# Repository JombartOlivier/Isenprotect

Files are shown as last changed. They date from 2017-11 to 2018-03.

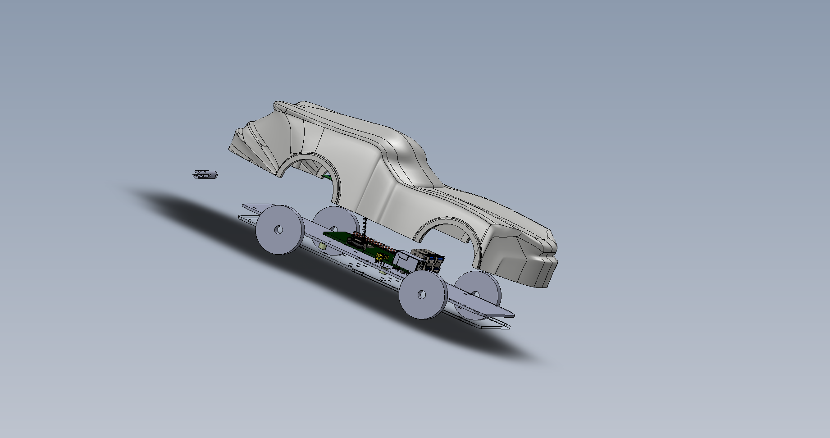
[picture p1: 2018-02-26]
Solidworks/VOITURE2.PNG

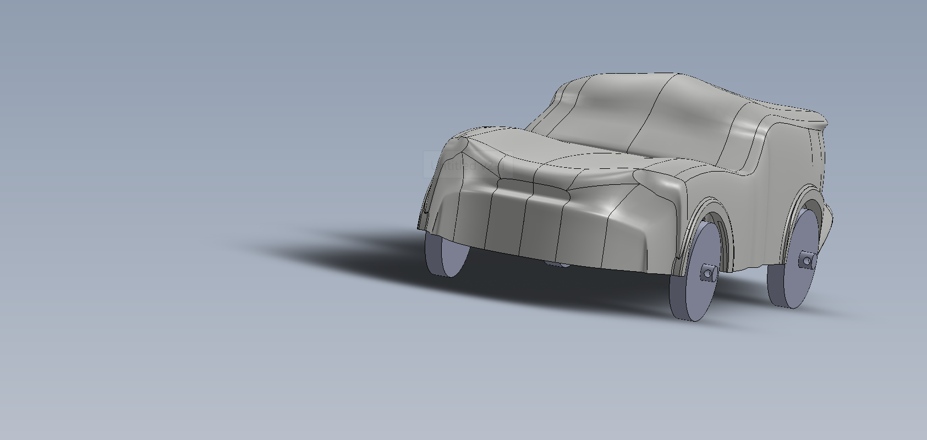
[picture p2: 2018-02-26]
Solidworks/VOITURE.PNG

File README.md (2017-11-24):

IsenProtect
==
Goal
-
The goal of this project is to make a devices who save your life in case of a car accident. 
We make a crash dectetor whit a IMU 6 axis if a crash is dected and the user don't press a buttons in 1 minute after the crash.
The devices send an alert the rescuer.
The project is a Isen Project.

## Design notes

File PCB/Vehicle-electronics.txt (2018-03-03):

- le nom de l'archive d¨¦pos¨¦e
Vehicle-electronics

- les dimensions approximatives du circuit (pour v¨¦rification apr¨¨s importation)
57.2 x 86.5mm

- le nombre d'exemplaires d¨¦sir¨¦s
2

- le mail du r¨¦f¨¦rent projet (encadrant)
annemarie.kokosy@yncrea.fr

- le mail du responsable technique, c'est ¨¤ dire la personne ¨¤ contacter en cas de probl¨¨me lors de la r¨¦alisation du circuit
cong.chen@isen.yncrea.fr

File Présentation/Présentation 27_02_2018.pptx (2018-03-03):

## ISENPROTECT

Olivier Jombart / Cong Chen / Arthur Duystchaever

## Sommaire

1. Objectifs
2. Concept
3. Ordinateur embarqué
4. Détecteur de chocs
5. GPS
6. Transmission des données
7. Autres fonctionnalités
8. Intégration

## Objectifs

- Concevoir un système capable d’émettre un SOS en cas d’accident
- Diminuer le temps entre la détection de l’accident et l’intervention des secours
- Diminuer le risque de mortalité sur la route

## Concept

GPS

Capteur de chocs

Processeur

Envoie des coordonnées GPS

Button momentanné

Avertisseur Sonore

## Ordinateur embarqué

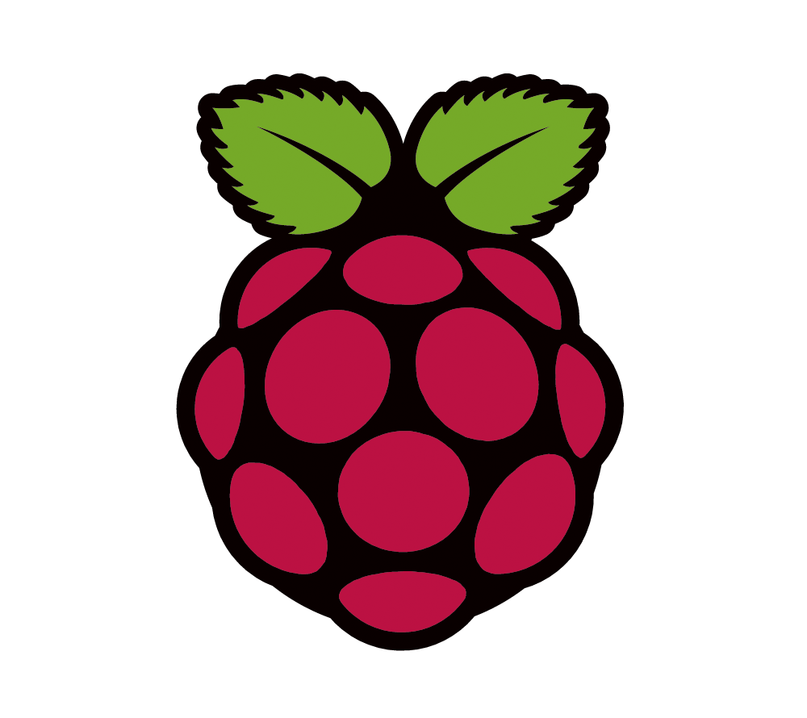
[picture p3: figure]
Résultat de recherche d'images pour "raspberry pi3 logo png"

- Raspberry PI3
- OS : Raspbian
- Processeur : ARM Quad Core 1,2 GHz

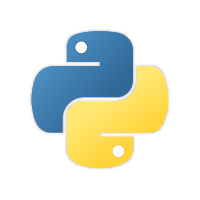
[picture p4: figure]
Résultat de recherche d'images pour "python"
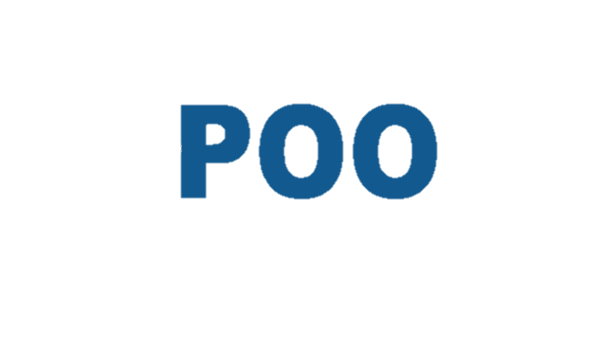
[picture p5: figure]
Résultat de recherche d'images pour "orienté objet"

## Détecteur de chocs

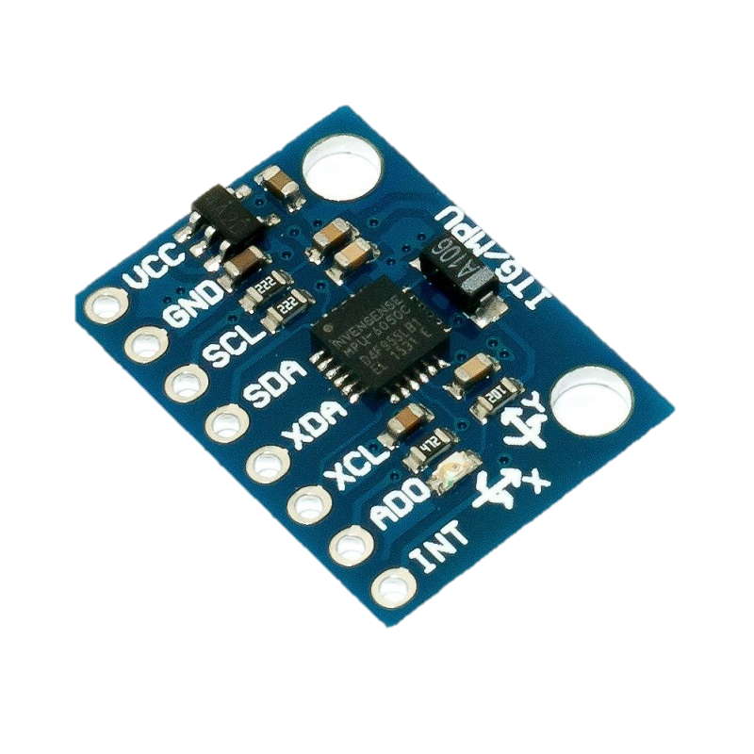
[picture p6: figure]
Résultat de recherche d'images pour "mpu6050 ITG"

- MPU6050 (ITG)
- Communication : I2C
- IMU 6 axes : accéléromètre, gyroscope

## GPS

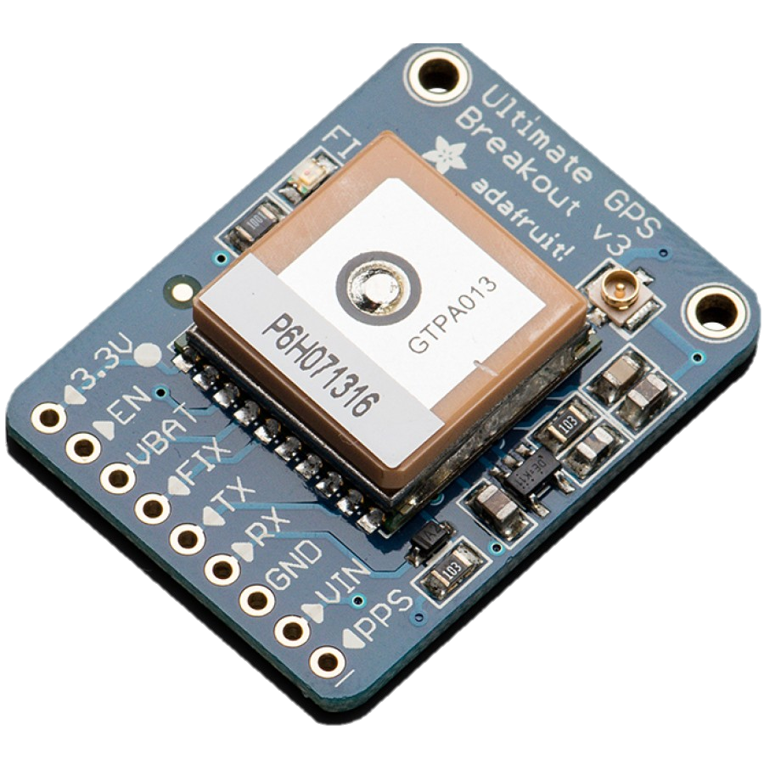
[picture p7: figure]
Résultat de recherche d'images pour "gps adafruit png"

- GPS : Adafruit 746
- Communication : UART
- Baud Rate : 9600

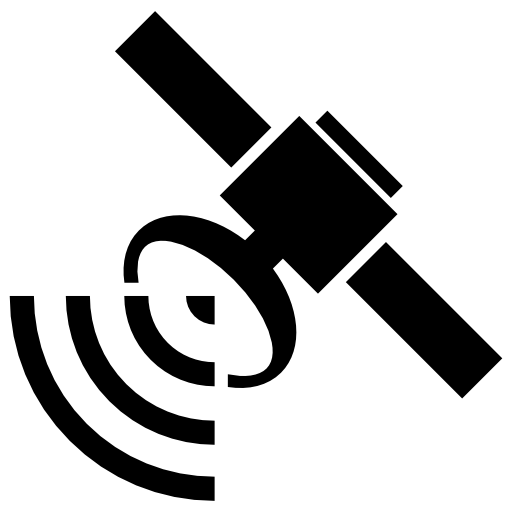
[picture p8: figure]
Résultat de recherche d'images pour "GPS PNG"

$GPRMC,194509.000,A,4042.6142,N,07400.4168,E,2.03,221.11,280218,,,A*77

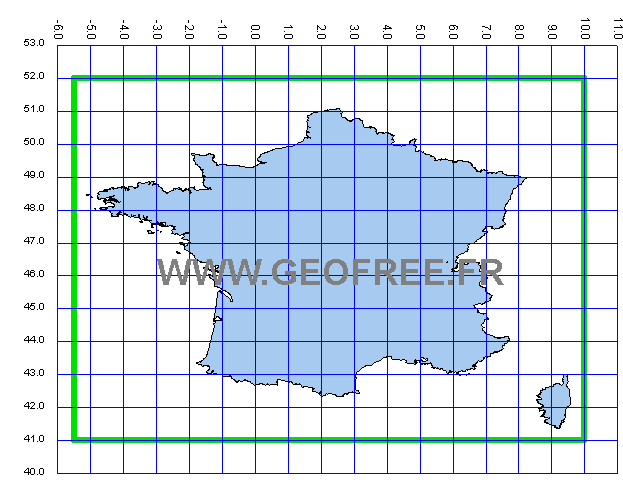
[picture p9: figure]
Résultat de recherche d'images pour "france coordonnées géographique"

## Transmission des données

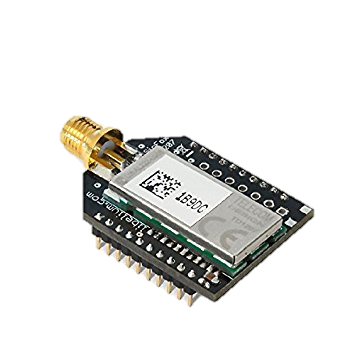
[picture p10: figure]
Résultat de recherche d'images pour "module sigfox"

- SigFox
- Communication : UART
- Baud Rate : 115200

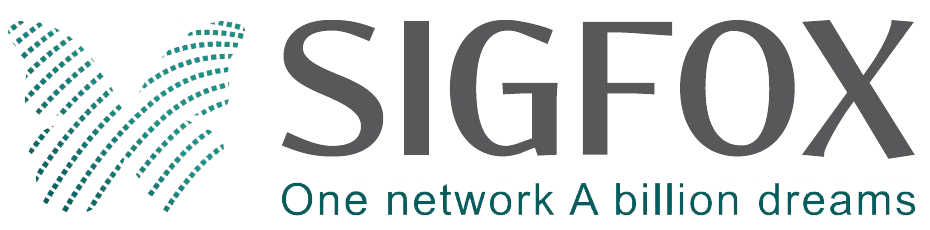
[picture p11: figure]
Résultat de recherche d'images pour "sigfox png"
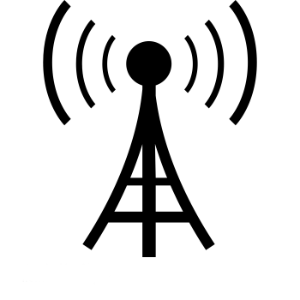
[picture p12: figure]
Résultat de recherche d'images pour "antennes png"
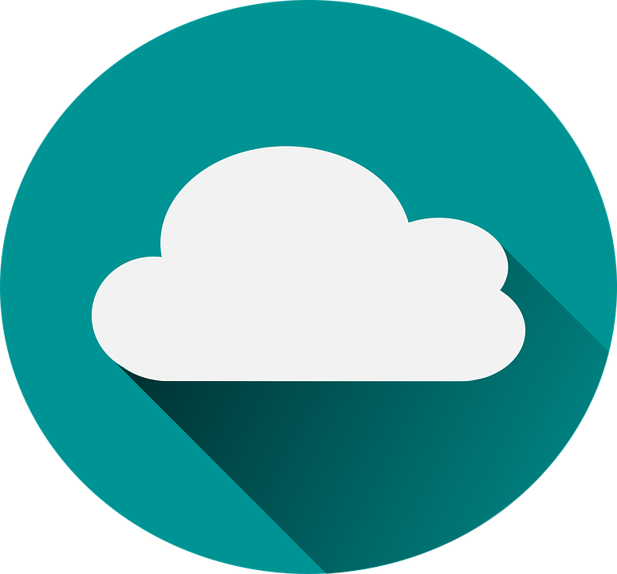
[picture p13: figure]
Résultat de recherche d'images pour "cloud logo png"
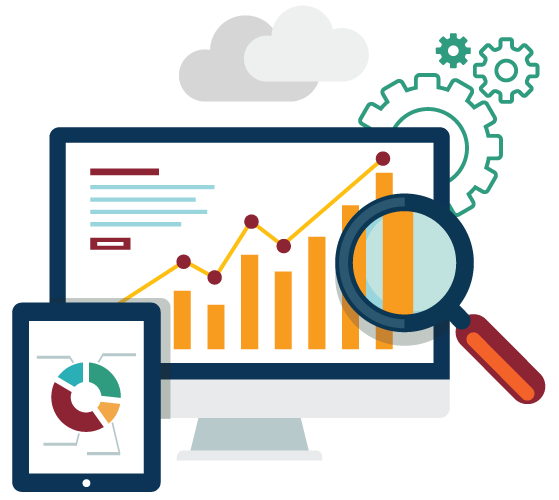
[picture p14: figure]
Résultat de recherche d'images pour "monitoring png"

## Autres fonctionnalités

- Bouton Momentané avec LED intégré
- Avertisseur sonore

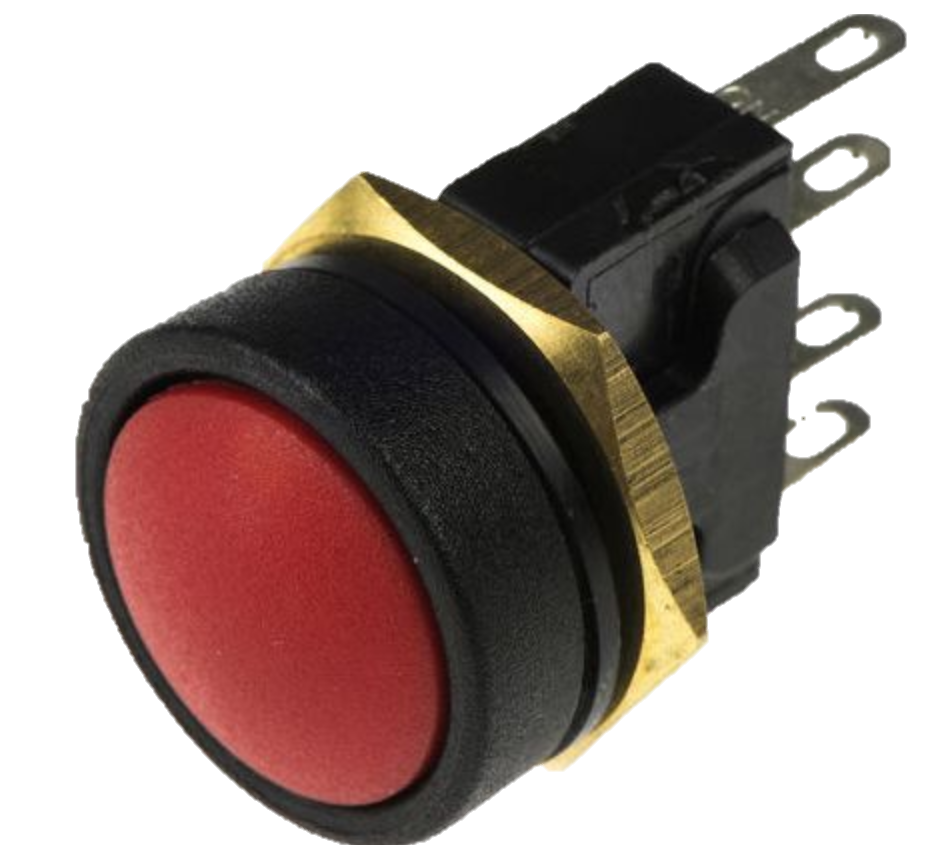
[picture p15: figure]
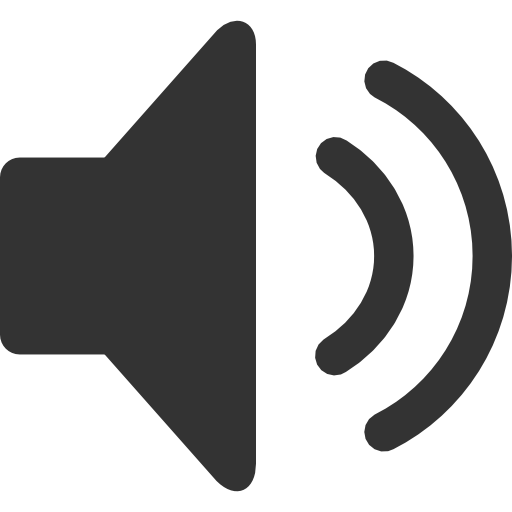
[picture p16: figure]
Résultat de recherche d'images pour "haut parleur png"

## Intégration

GPS

UART : RX-> TX

IMU

I2C

Raspberry + Shield

UART : TX-> RX

Sigfox

GPIO

HDMI ou Jack

Enceintes

Button momentanné

## Conclusion

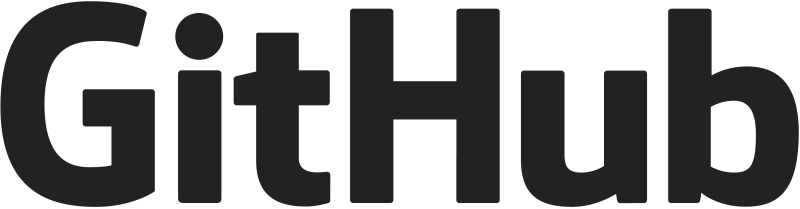
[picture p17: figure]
Résultat de recherche d'images pour "github png"
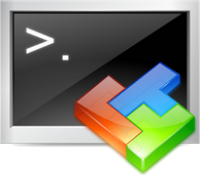
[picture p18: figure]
Résultat de recherche d'images pour "mobaxterm png"
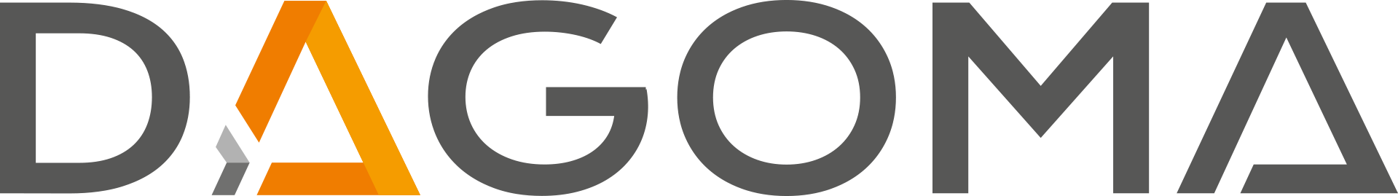
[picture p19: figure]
Résultat de recherche d'images pour "dagoma png"
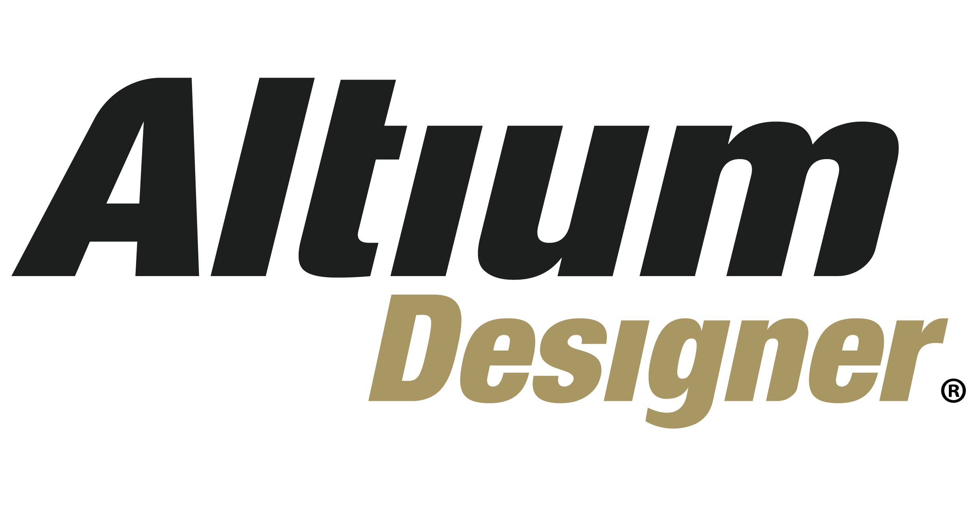
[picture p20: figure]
Résultat de recherche d'images pour "altium designer png"

## Démonstration


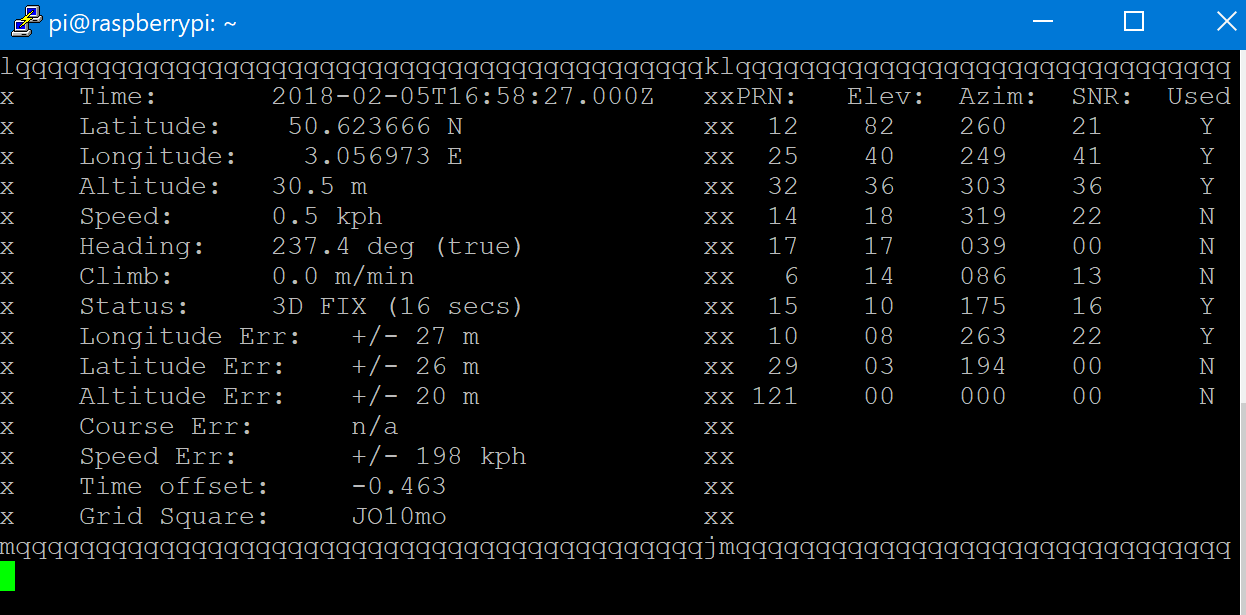
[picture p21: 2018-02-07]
Documentation/GPS WORKS.PNG

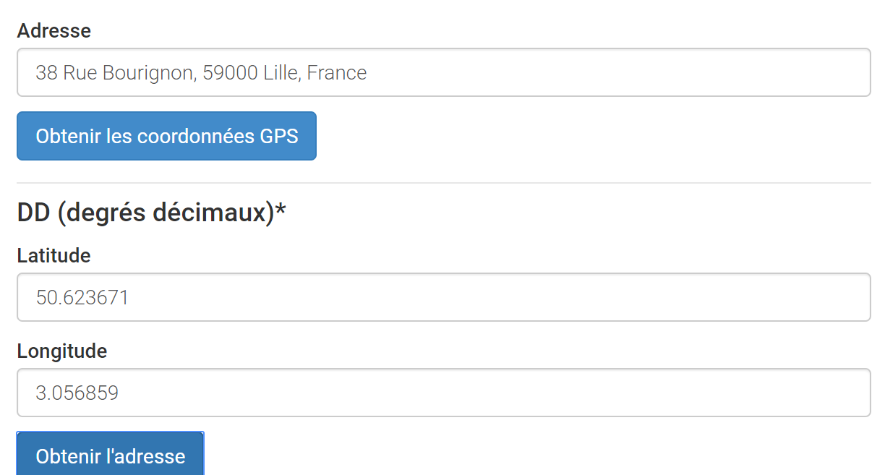
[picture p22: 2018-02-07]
Documentation/GPS2WORKS.PNG

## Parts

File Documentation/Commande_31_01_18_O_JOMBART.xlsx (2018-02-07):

Decription | N° produit | Lien | Quantité | Prix
Radiospare
Bouton Poussoir momentané | 228-4632 | https://fr.rs-online.com/web/p/interrupteurs-a-bouton-poussoir/2284632/ | 1 | 9.52 €
MPU-6050 | 883-7948 | https://fr.rs-online.com/web/p/accelerometres/8837948/ | 3 | 8.19 €
Total |  |  | 4 | 34.09 €

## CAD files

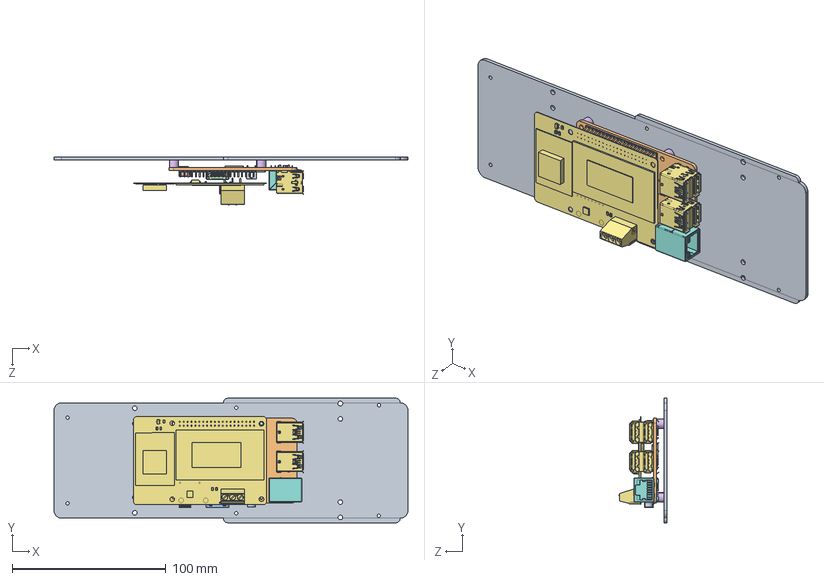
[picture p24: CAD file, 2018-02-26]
Solidworks/Assemblage socle rasp.SLDASM
230.0 x 81.0 x 31.5 mm
socle
carte_mere
HDMI_socket_cover
HDMI_socket_inside
HDMI_socket_large_pin x 10
HDMI_socket_small_pin x 9
usb3x2 x 2
RJ45_10P_TJ3009
PCB_Stereo_Jack_(body)
PCB_Stereo_Jack_(GND_contact)
PCB_Stereo_Jack_(channel_contact_2)
PCB_Stereo_Jack_(channel_contact_1)
USB
Pièce espacement raspberry pi x 4
vehicle electronics

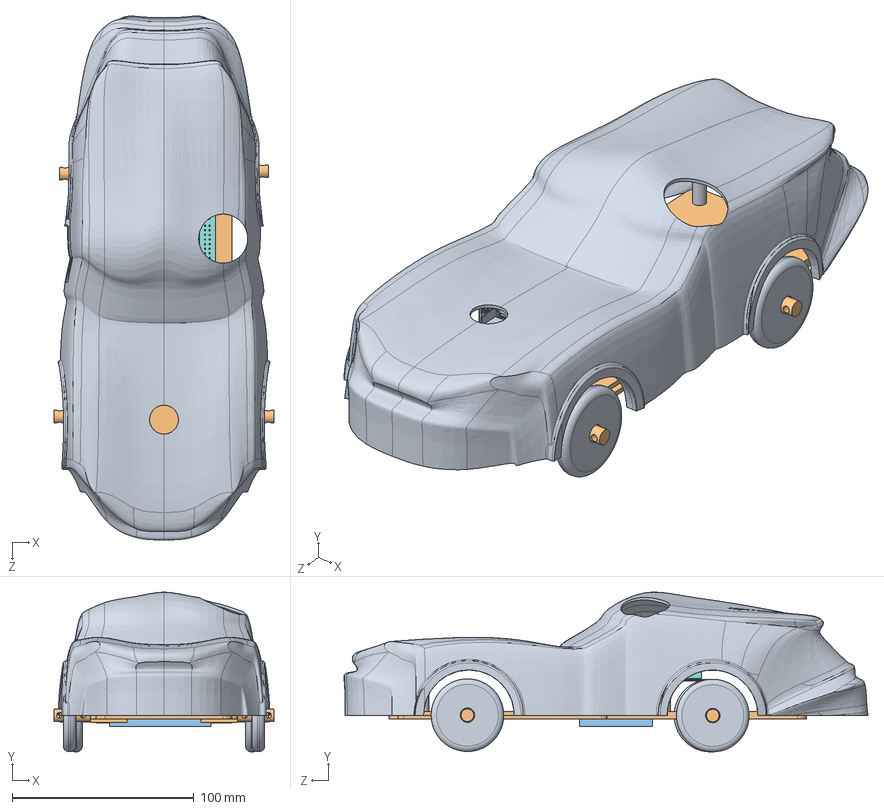
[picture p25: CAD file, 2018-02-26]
Solidworks/Assemblage finale.SLDASM
121.0 x 88.0 x 288.7 mm
Coqueavant
socle
carte_mere
HDMI_socket_cover
HDMI_socket_inside
HDMI_socket_large_pin x 10
HDMI_socket_small_pin x 9
usb3x2 x 2
RJ45_10P_TJ3009
PCB_Stereo_Jack_(body)
PCB_Stereo_Jack_(GND_contact)
PCB_Stereo_Jack_(channel_contact_2)
PCB_Stereo_Jack_(channel_contact_1)
USB
Pièce espacement raspberry pi x 4
vehicle electronics
Wheel x 4
Arbre x 4
Support socle x 2

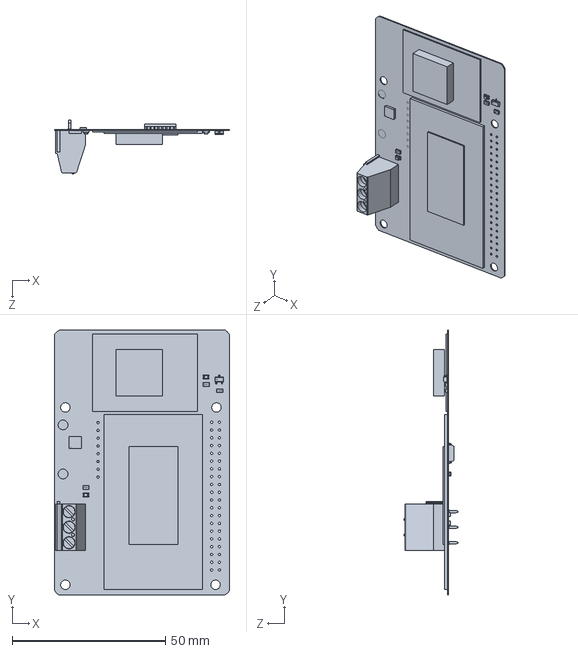
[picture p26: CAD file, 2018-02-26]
Solidworks/vehicle electronics.SLDPRT
57.2 x 86.5 x 17.7 mm

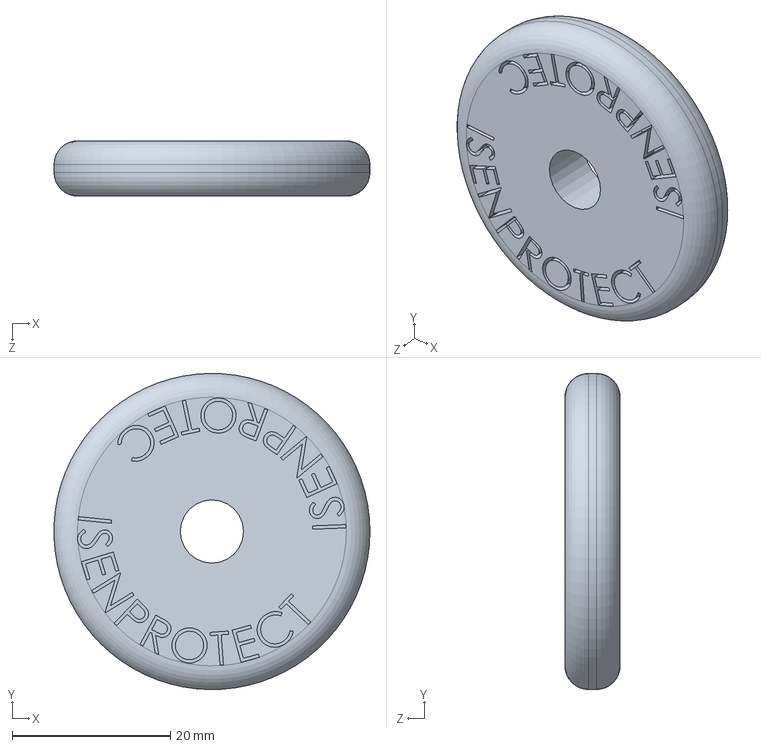
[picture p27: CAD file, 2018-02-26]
Solidworks/Wheel.SLDPRT
40.0 x 40.0 x 7.00 mm

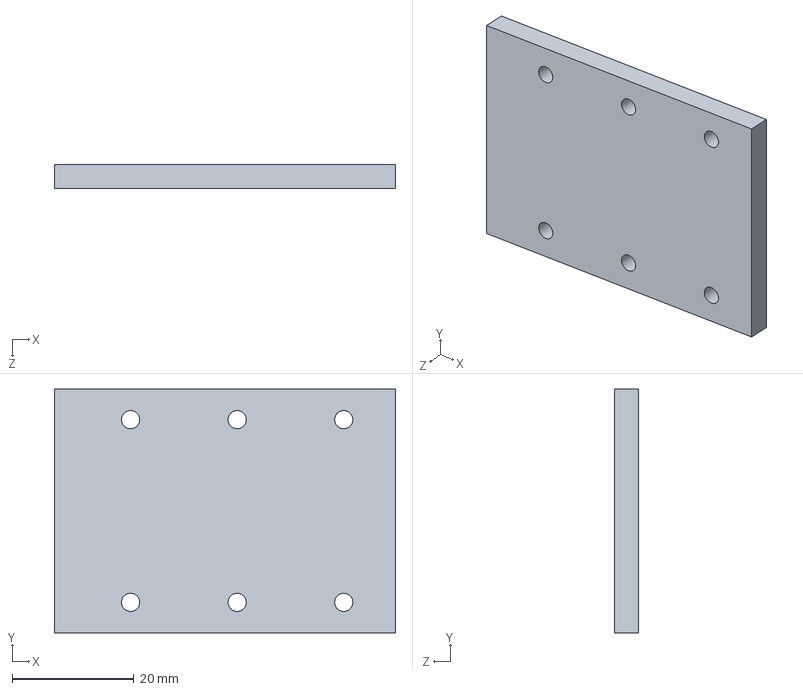
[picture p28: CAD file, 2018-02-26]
Solidworks/Support socle.SLDPRT
56.0 x 40.0 x 4.00 mm

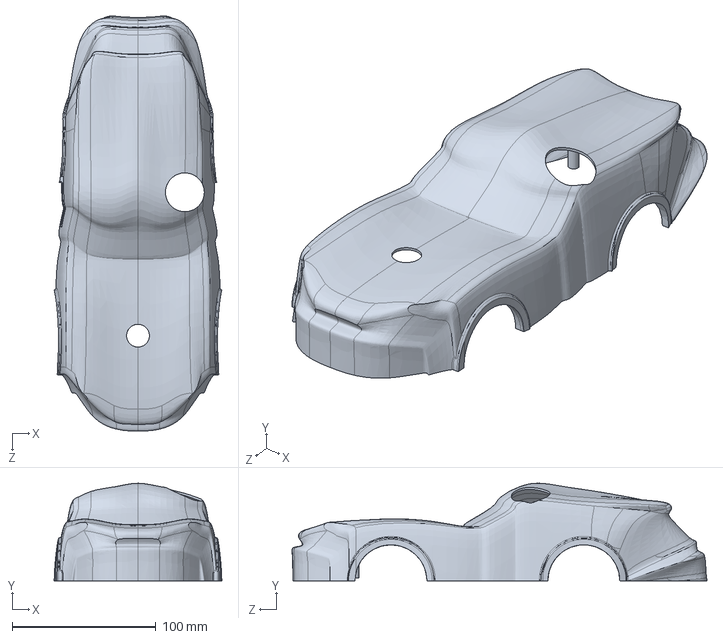
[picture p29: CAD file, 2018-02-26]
Solidworks/Coqueavant.SLDPRT
116.6 x 67.9 x 288.7 mm

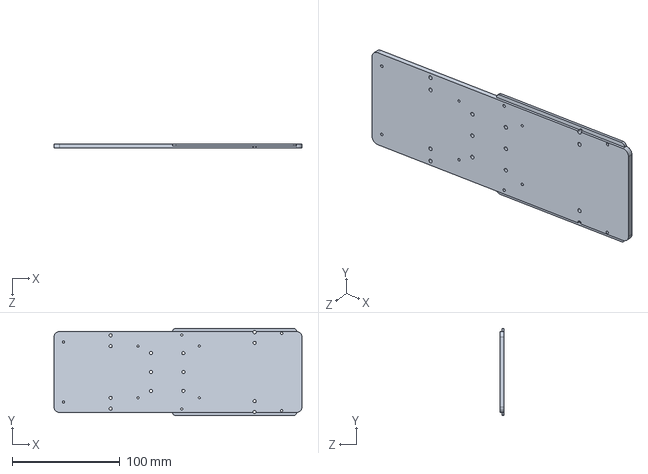
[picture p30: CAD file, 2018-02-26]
Solidworks/socle.SLDPRT
230.0 x 81.0 x 4.00 mm

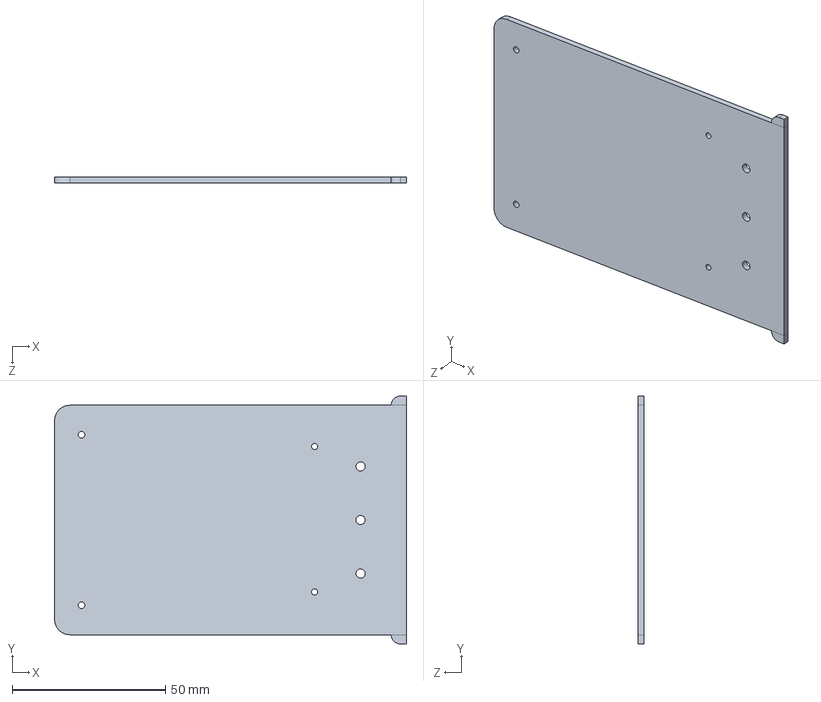
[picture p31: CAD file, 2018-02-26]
Solidworks/SOCLE2.STL.SLDPRT
115.0 x 81.0 x 2.00 mm

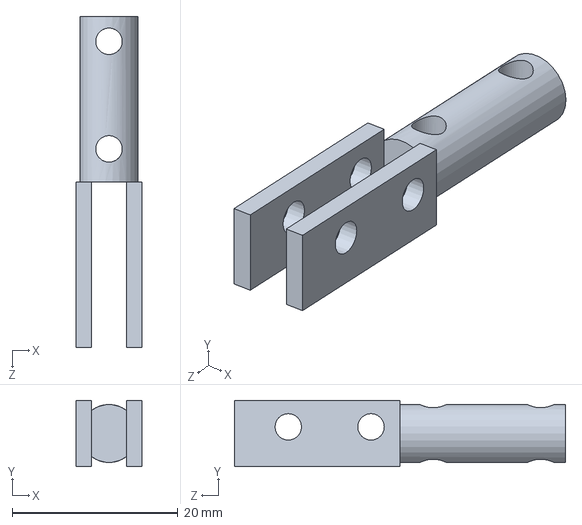
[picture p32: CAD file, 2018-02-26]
Solidworks/Arbre.SLDPRT
8.00 x 8.00 x 40.0 mm

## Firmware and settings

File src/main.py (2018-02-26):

#!/usr/bin/env python
# -*- coding: utf-8 -*-
#

import SigfoxCom
import serial
from imu import *
from mpu6050 import mpu6050
from apresDetection4 import *
import RPi.GPIO as GPIO  
import time 
import GPS1_2
 
sigfox = SigfoxCom.Sigfox
gps = GPS1_2.GPS

ledGpioNumber = 26
boutonNumber = 25

#setting GPIO
GPIO.setmode(GPIO.BCM)
GPIO.setwarnings(False)
GPIO.setup(ledGpioNumber,GPIO.OUT) 							   #LED du bouton
GPIO.setup(boutonNumber, GPIO.IN, pull_up_down=GPIO.PUD_DOWN)

#setting Multiplexeur
GPIOenableMultiplexeur = 17
GPIO.setup(GPIOenableMultiplexeur, GPIO.OUT)



tempAttente = 20
# Imu declaration
imuAddr = 0x68
averageAcceleration = []
averageGyroscope = []
imu = mpu6050(imuAddr)


state = 0

averageGyroscope, averageAcceleration = imuCalibration(imu) 

# Define a threaded callback function to run in another thread when events are detected  
def my_callback(cha): 
	global state
	state=3
	
    

#detection changement d'état et appel de la fonction callback
GPIO.add_event_detect(boutonNumber, GPIO.RISING, callback=my_callback)
finProgramme = True
print("etat : ",state)
while finProgramme == True:
	#print("etat : ", state)	
	#etat de detection d'accident via l'IMU
	if state == 0:
		state = isCrash(imu, averageAcceleration, averageGyroscope)
		GPIO.output(ledGpioNumber,GPIO.LOW)
		temp = time.time()
	elif state == 1:
		print("etat : ",state)
		GPIO.output(ledGpioNumber,GPIO.HIGH)
		play_music(state)
		x= int(time.time() - temp)
		print("temps d'attente :", x)
		if (time.time() - temp) > tempAttente:
			state = 2
        
    #etat si l'utilisateur n'a pas appuyé sur le bouton   
	elif state == 2:
		print("etat : ",state)
		GPIO.output(GPIOenableMultiplexeur, GPIO.LOW)
		GPIO.output(ledGpioNumber, GPIO.LOW)
		play_music(state)
		gps.setDataGps(gps)
		lattitude = gps.lattitude
		longitude = gps.longitude
		coordonnees = lattitude + longitude
		# close port
		print("lattitude : ", lattitude)
		print("longitude : ", longitude)
		sleep(0.5)
		GPIO.output(ledGpioNumber, GPIO.HIGH)
		sigfox.openUartPort(sigfox, "/dev/ttyAMA0", 115200, 2)
		sleep(0.5)
		sigfox.wakeUpSigfox(sigfox)
		sigfox.sendData(sigfox, coordonnees)
		sigfox.closeUartPort(sigfox)
		GPIO.output(ledGpioNumber,GPIO.LOW)
		finProgramme = False
	#etat si l'utilisateur a appuyé sur le bouton
	elif state == 3:
		print("etat : ",state)
		GPIO.output(ledGpioNumber,GPIO.LOW)
		play_music(state)
		state = 0 #on revient à l'état 1
		print("etat : ",state)

        





    

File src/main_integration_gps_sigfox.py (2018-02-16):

#!/usr/bin/env python
# -*- coding: utf-8 -*-
#

import GPS1_2

import SigfoxCom
a = GPS1_2.GPS
b= SigfoxCom.Sigfox
a.setDataGps(a)
a._get_lattitude(a)
a._get_longitude(a)
a._set_lattitude(a,"553520")
a._set_longitude(a,"034343")
b.openUartPort(b,"/dev/ttyAMA0", 115200, 2)
b.wakeUpSigfox(b)
b.sendData(b,a._get_longitude(a))
b.closeUartPort(b)

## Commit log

2017-11-24 Add List of material
    [Liste Materiel.xlsx]
2017-11-24 Compute the price
    [Liste Materiel.xlsx]
2018-01-14 Add first test to the UART (port ttyAMA0)
2018-01-14 Test UART with C program
2018-01-15 New lib to use uart (working expect receiveData bug on the return)
2018-01-29 correct some bugs on the sendData
    [testUARTWithC.c]
2018-02-04 first test with sigfox not working
    [SigfoxCom.py, main.py]
2018-02-05 scr/Button : add scripts
    [Commande_31_01_18_O_JOMBART.xlsx, Liste Materiel.xlsx]
2018-02-05 update button
2018-02-12 Update class bouton, issue : interruption
    [apresDetection3.py, button.py]
2018-02-13 add IMU
2018-02-14 Add test gyroscope
2018-02-16 update last version button
2018-02-16 add new version of play musique
    [apresDetection4.py]
2018-02-16 last version not working bug in call of mpu librairy
    [GPS1_2.py, apresDetection4.py, imu.py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]
2018-02-17 correct some syntax error
    [imu.py, main.py]
2018-02-19 Add folder solidworks
    [Arbre.SLDPRT, Assemblage finale.SLDASM, Assemblage socle rasp.SLDASM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]
2018-02-21 Update main and fix bugs. New issue : global state for the button
    [apresDetection4.py, imu.py, main.py]
2018-02-21 button fixed and new visual on the console
    [GPS1.2.py, SigfoxCom.py, main.py]
2018-02-26 switch logic state on multiplexor
2018-02-27 Add pcb
